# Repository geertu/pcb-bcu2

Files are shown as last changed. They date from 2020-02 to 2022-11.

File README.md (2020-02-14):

# BCU/2 - Board Control Unit Duo (KiCad PCB)

This is a small board to control operation of two development boards, e.g. on
your desk, or in a board farm.

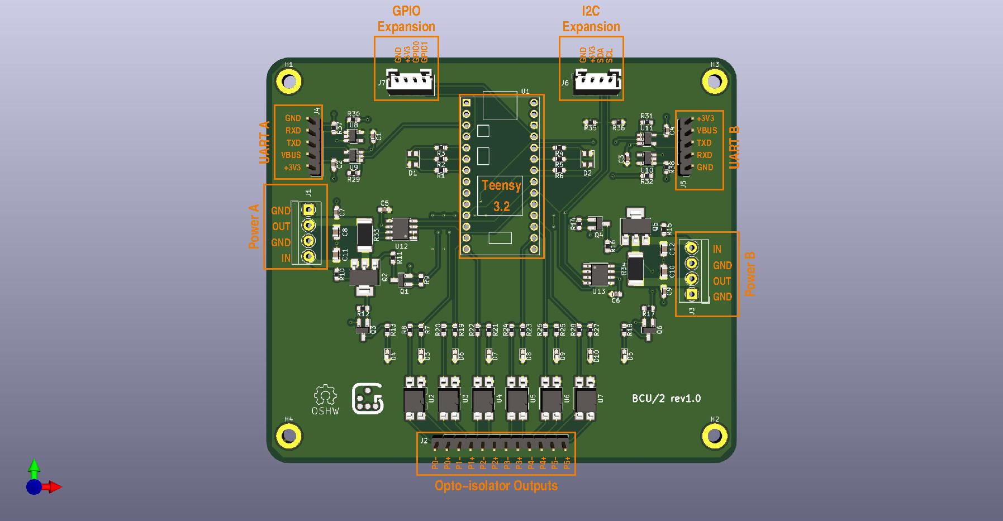
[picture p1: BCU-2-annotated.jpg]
PCB


## Features

  - Controlled by a Teensy 3.2 (https://www.pjrc.com/store/teensy32.html),
  - Two power control and measurement channels (3.3-14V, max. 3.2A),
  - Two UART channels
      - Optional buffer circuitry supports 1.8 to 5V, or fixed 3.3V,
      - Add external MAX3232 board for RS232-compatible voltage levels.
  - Six opto-isolators for e.g. reset, wake-up, and keypress simulation,
  - Two RGB status LEDs,
  - 4-pin I2C expansion connector,
  - 4-pin GPIO expansion connector.

## Software

Software to run on the Teensy is available from
https://github.com/geertu/teensy3-bcu2 in source form.

## License

CC-BY-SA-4.0 (https://creativecommons.org/licenses/by-sa/4.0/)

## PCB and Parts

PCB and parts can be ordered at
https://aisler.net/geert/board-control-unit/bcu-2 (Disclaimer: I'm not
affiliated to AISLER)

## Bill Of Materials

  - C1-C4[A], C5-C7, C9: Capacitor, 100nF, SMD 0603/1608
  - C8, C10-C12: Capacitor, 10µF, SMD 0805/2012, 25V
  - D1, D2: LED RGB Diffused, Common Anode at pin 1, SMD 4PLCC
  - D3, D6-D10: LED Yellow clear, SMD 0603/1608
  - D4, D5: LED Green clear, SMD 0603/1608
  - J1, J3: Screw type, terminal block, RM 3.5mm
  - J2: Male 1x12 header 2.54mm
  - J4, J5: Male 1x5 header, RM 2.54mm
  - J6, J7: Male 1x4 header, RM 2mm, e.g. JST B4B-PH-K
  - J8-J9[B]: Male 1x14 header, RM 2.54mm
  - J10-J11[B]: Female 1x14 header, RM 2.54mm
  - Q1, Q3, Q4, Q6: MOSFET N-channel 60V 115mA, SOT23-3
  - Q2, Q5: MOSFET P-channel 20V 10A, SOT223
  - R1, R4: Resistor, 680Ω, SMD 0603/1608
  - R2, R3, R5, R6: Resistor, 100Ω, SMD 0603/1608
  - R7, R13, R18, R19, R21, R23, R25, R27: Resistor, 1kΩ, SMD 0603/1608
  - R8, R20, R22, R24, R26, R28: Resistor, 270Ω, SMD 0603/1608
  - R9, R14: Resistor, 10kΩ, SMD 0603/1608
  - R10, R11, R15, R16, R37[A], R38[A]: Resistor, 47kΩ, SMD 0603/1608
  - R12, R17: Resistor, 100kΩ, SMD 0603/1608
  - R29-R32[C]: Resistor, 0Ω, SMD 0603/1608
  - R33, R34: Resistor, 100mΩ, SMD 2512/6432, 1%, 2W
  - R35, R36: Resistor, 4.7kΩ, SMD 0603/1608
  - U1: Teensy 3.2
  - U2-U7: Opto-isolator, Mini-Flat-4, e.g. Broadcom HCPL-181-00CE
  - U8-U11[A]: 2-input AND gate 74LV1T08[D], SOT23-5
  - U12, U13: INA219xID power monitor, 8-SOIC

## Connector pinouts

  - J1 / J3: Power channels A & B

    Pin | Function
    --- | --------
     1  | GND
     2  | Power OUT
     3  | GND
     4  | Power IN (3.3-14V, max. 3.2A)

  - J2: Opto-isolator channels 0-5

    Pin               | Function
    ----------------- | --------
     1-11 (odd pins)  | Emitter ("negative output")
     2-12 (even pins) | Collector ("positive output")

  - J4 / J5: UART channels A & B

    Pin | Function
    --- | --------
     1  | GND
     2  | RXD
     3  | TXD
     4  | VBUS (1.8V to 5V), may be jumpered to +3V3
     5  | +3.3V[E]

  - J6: I2C expansion[F]

    Pin | Function
    --- | --------
     1  | GND
     2  | +3.3V[E]
     3  | SDA
     4  | SCL

  - J7: GPIO expansion[F]

    Pin | Function
    --- | --------
     1  | GND
     2  | +3.3V[E]
     3  | GPIO0
     4  | GPIO1

## Footnotes

  * [A] Optional buffer circuitry, mutually exclusive with [C]
  * [B] For Teensy plugin, not on schematic
  * [C] Optional buffer bypass, mutually exclusive with [A]
  * [D] Replace by 74LV1T00 for inverted TXD/RXD logic
  * [E] Maximum current output on the +3.3V pin of the Teensy 3.2 is 250 mA.
	Up to 100-125 mA can be used by expansion peripherals.
  * [F] Pin order of the I2C and GPIO expansion connectors is similar (but
	reversed!) to the Seeed Studio Grove and SparkFun Qwiic Connect
	systems, although the connector used is different (you can probably
	mount a real Grove connector instead).

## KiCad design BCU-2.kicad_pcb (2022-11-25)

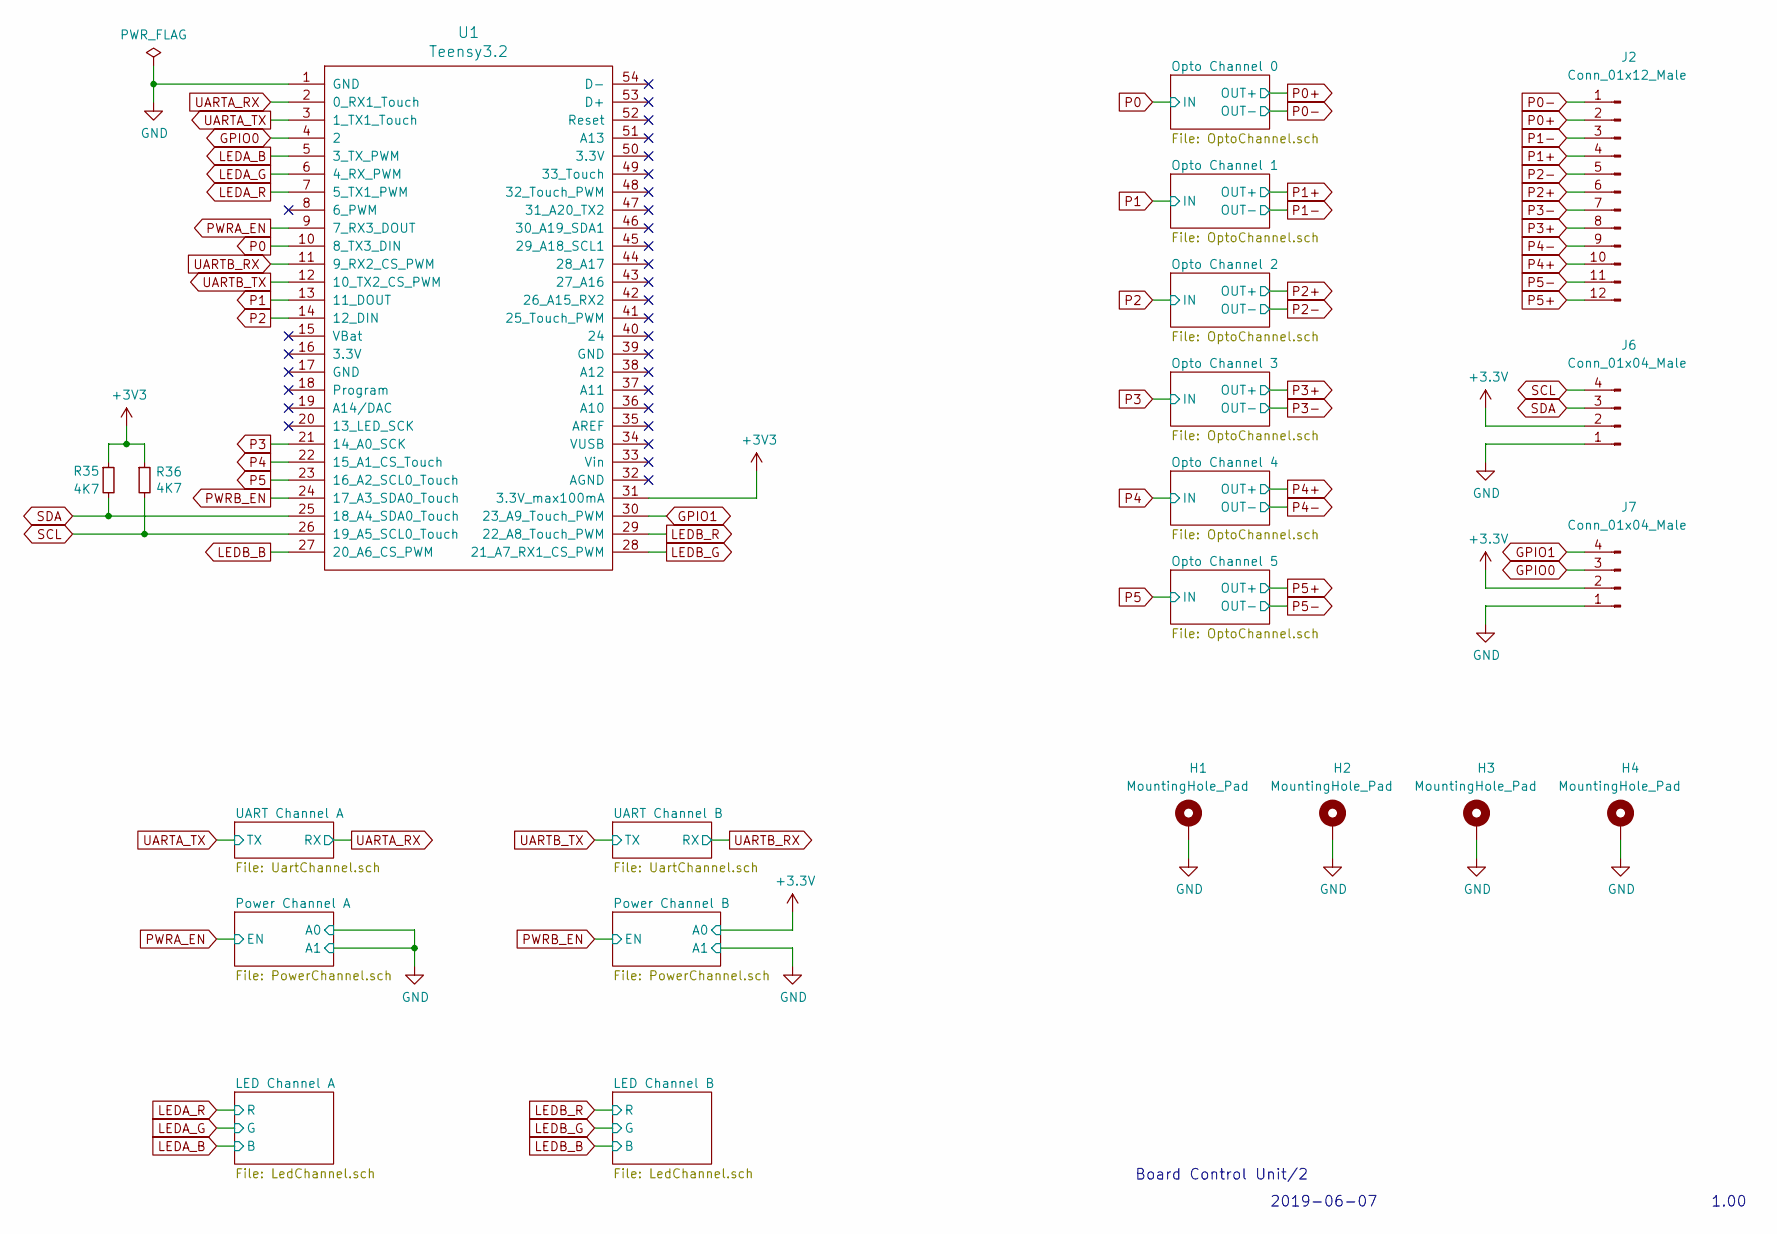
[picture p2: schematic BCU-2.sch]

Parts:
H1, H2, H3, H4: MountingHole_Pad; MountingHole_3.2mm_M3_DIN965_Pad
J2: Conn_01x12_Male; PinHeader_1x12_P2.54mm_Vertical
J6, J7: Conn_01x04_Male; JST_PH_B4B-PH-K_1x04_P2.00mm_Vertical
R35, R36: 4K7; R_0603_1608Metric_Pad1.05x0.95mm_HandSolder
U1: Teensy3.2; Teensy32-DIP28

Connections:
+3V3: J6.2, J7.2, R35.1, R36.1, U1.31 (3.3V_max100mA); also elsewhere on the board
GND: H1.1, H2.1, H3.1, H4.1, J6.1, J7.1, U1.1 (GND); also elsewhere on the board
GPIO0: J7.3, U1.4 (2)
GPIO1: J7.4, U1.30 (23_A9_Touch_PWM)
LEDA_B: U1.5 (3_TX_PWM); also elsewhere on the board
LEDA_G: U1.6 (4_RX_PWM); also elsewhere on the board
LEDA_R: U1.7 (5_TX1_PWM); also elsewhere on the board
LEDB_B: U1.27 (20_A6_CS_PWM); also elsewhere on the board
LEDB_G: U1.28 (21_A7_RX1_CS_PWM); also elsewhere on the board
LEDB_R: U1.29 (22_A8_Touch_PWM); also elsewhere on the board
P0: U1.10 (8_TX3_DIN); also elsewhere on the board
P0+: J2.2; also elsewhere on the board
P0-: J2.1; also elsewhere on the board
P1: U1.13 (11_DOUT); also elsewhere on the board
P1+: J2.4; also elsewhere on the board
P1-: J2.3; also elsewhere on the board
P2: U1.14 (12_DIN); also elsewhere on the board
P2+: J2.6; also elsewhere on the board
P2-: J2.5; also elsewhere on the board
P3: U1.21 (14_A0_SCK); also elsewhere on the board
P3+: J2.8; also elsewhere on the board
P3-: J2.7; also elsewhere on the board
P4: U1.22 (15_A1_CS_Touch); also elsewhere on the board
P4+: J2.10; also elsewhere on the board
P4-: J2.9; also elsewhere on the board
P5: U1.23 (16_A2_SCL0_Touch); also elsewhere on the board
P5+: J2.12; also elsewhere on the board
P5-: J2.11; also elsewhere on the board
PWRA_EN: U1.9 (7_RX3_DOUT); also elsewhere on the board
PWRB_EN: U1.24 (17_A3_SDA0_Touch); also elsewhere on the board
SCL: J6.4, R36.2, U1.26 (19_A5_SCL0_Touch); also elsewhere on the board
SDA: J6.3, R35.2, U1.25 (18_A4_SDA0_Touch); also elsewhere on the board
UARTA_RX: U1.2 (0_RX1_Touch); also elsewhere on the board
UARTA_TX: U1.3 (1_TX1_Touch); also elsewhere on the board
UARTB_RX: U1.11 (9_RX2_CS_PWM); also elsewhere on the board
UARTB_TX: U1.12 (10_TX2_CS_PWM); also elsewhere on the board

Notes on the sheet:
Board Control Unit/2
2019-06-07
1.00

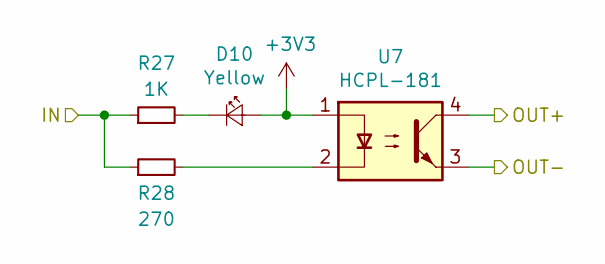
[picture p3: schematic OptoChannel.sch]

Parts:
D3: Yellow; LED_0603_1608Metric_Castellated
R7: 1K; R_0603_1608Metric_Pad1.05x0.95mm_HandSolder
R8: 270; R_0603_1608Metric_Pad1.05x0.95mm_HandSolder
U2: HCPL-181; SMDIP-4_W7.62mm

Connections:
+3V3: D3.2 (A), U2.1; also elsewhere on the board
unnamed: D3.1 (K), R7.2
unnamed: R8.2, U2.2
P0: R7.1, R8.1; also elsewhere on the board
P0+: U2.4; also elsewhere on the board
P0-: U2.3; also elsewhere on the board

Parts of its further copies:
D6, D7, D8, D9, D10: Yellow; LED_0603_1608Metric_Castellated
R19, R21, R23, R25, R27: 1K; R_0603_1608Metric_Pad1.05x0.95mm_HandSolder
R20, R22, R24, R26, R28: 270; R_0603_1608Metric_Pad1.05x0.95mm_HandSolder
U3, U4, U5, U6, U7: HCPL-181; SMDIP-4_W7.62mm

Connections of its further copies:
+3V3: D6.2 (A), D7.2 (A), D8.2 (A), D9.2 (A), D10.2 (A), U3.1, U4.1, U5.1, U6.1, U7.1; also elsewhere on the board
unnamed: D6.1 (K), R19.2
unnamed: D7.1 (K), R21.2
unnamed: D8.1 (K), R23.2
unnamed: D9.1 (K), R25.2
unnamed: D10.1 (K), R27.2
unnamed: R20.2, U3.2
unnamed: R22.2, U4.2
unnamed: R24.2, U5.2
unnamed: R26.2, U6.2
unnamed: R28.2, U7.2
P1: R19.1, R20.1; also elsewhere on the board
P1+: U3.4; also elsewhere on the board
P1-: U3.3; also elsewhere on the board
P2: R21.1, R22.1; also elsewhere on the board
P2+: U4.4; also elsewhere on the board
P2-: U4.3; also elsewhere on the board
P3: R23.1, R24.1; also elsewhere on the board
P3+: U5.4; also elsewhere on the board
P3-: U5.3; also elsewhere on the board
P4: R25.1, R26.1; also elsewhere on the board
P4+: U6.4; also elsewhere on the board
P4-: U6.3; also elsewhere on the board
P5: R27.1, R28.1; also elsewhere on the board
P5+: U7.4; also elsewhere on the board
P5-: U7.3; also elsewhere on the board

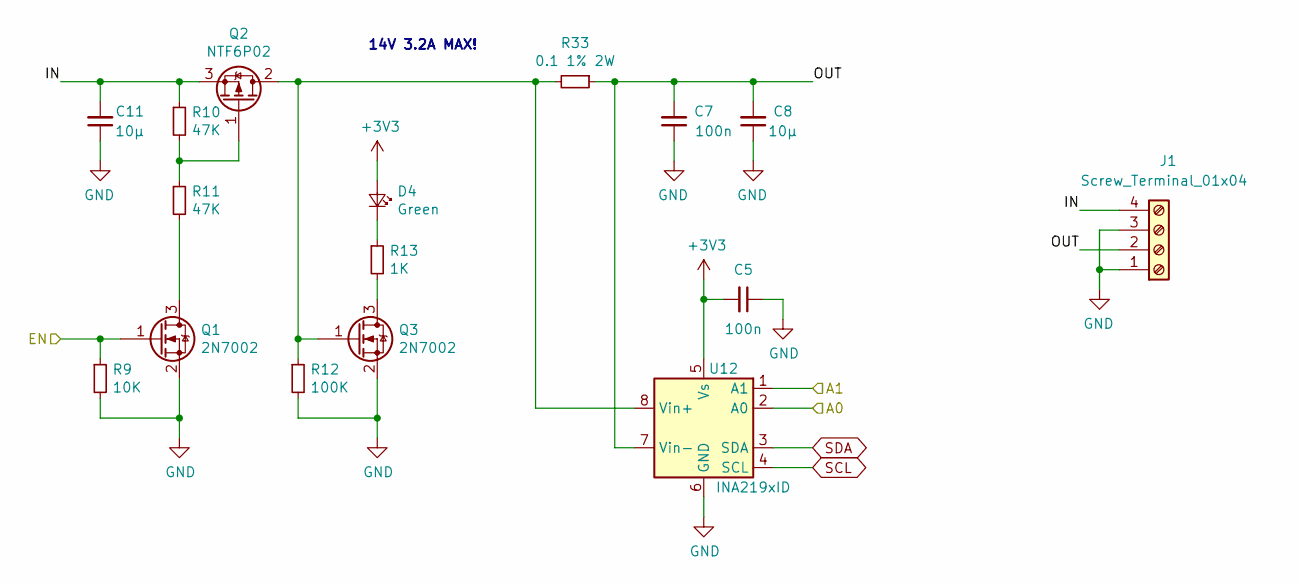
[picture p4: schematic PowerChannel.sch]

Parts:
C6, C9: 100n; C_0603_1608Metric_Pad1.05x0.95mm_HandSolder
C10, C12: 10µ; C_0805_2012Metric_Pad1.15x1.40mm_HandSolder
D4: Green; LED_0603_1608Metric_Castellated
J1: Screw_Terminal_01x04; TerminalBlock_MetzConnect_Type059_RT06304HBWC_1x04_P3.50mm_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
Q1, Q3: 2N7002; SOT-23_Handsoldering
Q2: NTF6P02; SOT-223-3_TabPin2
R9: 10K; R_0603_1608Metric_Pad1.05x0.95mm_HandSolder
R10, R11: 47K; R_0603_1608Metric_Pad1.05x0.95mm_HandSolder
R12: 100K; R_0603_1608Metric_Pad1.05x0.95mm_HandSolder
R13: 1K; R_0603_1608Metric_Pad1.05x0.95mm_HandSolder
R34: 0.1 1% 2W; R_2512_6332Metric_Pad1.52x3.35mm_HandSolder
U12: INA219xID; SOIC-8_3.9x4.9mm_P1.27mm

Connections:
+3V3: C6.2, D4.2 (A), U12.5 (Vs); also elsewhere on the board
GND: C6.1, C9.1, C10.1, C12.1, J1.1, J1.3, Q1.2 (S), Q3.2 (S), R9.2, R12.2, U12.1 (A1), U12.2 (A0), U12.6 (GND); also elsewhere on the board
unnamed: D4.1 (K), R13.1
unnamed: Q1.3 (D), R11.2
unnamed: Q2.1 (G), R10.2, R11.1
unnamed: Q3.3 (D), R13.2
PWRA_EN: Q1.1 (G), R9.1; also elsewhere on the board
SCL: U12.4 (SCL); also elsewhere on the board
SDA: U12.3 (SDA); also elsewhere on the board

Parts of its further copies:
C5, C7: 100n; C_0603_1608Metric_Pad1.05x0.95mm_HandSolder
C8, C11: 10µ; C_0805_2012Metric_Pad1.15x1.40mm_HandSolder
D5: Green; LED_0603_1608Metric_Castellated
J3: Screw_Terminal_01x04; TerminalBlock_MetzConnect_Type059_RT06304HBWC_1x04_P3.50mm_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
Q4, Q6: 2N7002; SOT-23_Handsoldering
Q5: NTF6P02; SOT-223-3_TabPin2
R14: 10K; R_0603_1608Metric_Pad1.05x0.95mm_HandSolder
R15, R16: 47K; R_0603_1608Metric_Pad1.05x0.95mm_HandSolder
R17: 100K; R_0603_1608Metric_Pad1.05x0.95mm_HandSolder
R18: 1K; R_0603_1608Metric_Pad1.05x0.95mm_HandSolder
R33: 0.1 1% 2W; R_2512_6332Metric_Pad1.52x3.35mm_HandSolder
U13: INA219xID; SOIC-8_3.9x4.9mm_P1.27mm

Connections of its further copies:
+3V3: C5.2, D5.2 (A), U13.2 (A0), U13.5 (Vs); also elsewhere on the board
GND: C5.1, C7.1, C8.1, C11.1, J3.1, J3.3, Q4.2 (S), Q6.2 (S), R14.2, R17.2, U13.1 (A1), U13.6 (GND); also elsewhere on the board
unnamed: D5.1 (K), R18.1
unnamed: Q4.3 (D), R16.2
unnamed: Q5.1 (G), R15.2, R16.1
unnamed: Q6.3 (D), R18.2
PWRB_EN: Q4.1 (G), R14.1; also elsewhere on the board
SCL: U13.4 (SCL); also elsewhere on the board
SDA: U13.3 (SDA); also elsewhere on the board

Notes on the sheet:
14V 3.2A MAX!

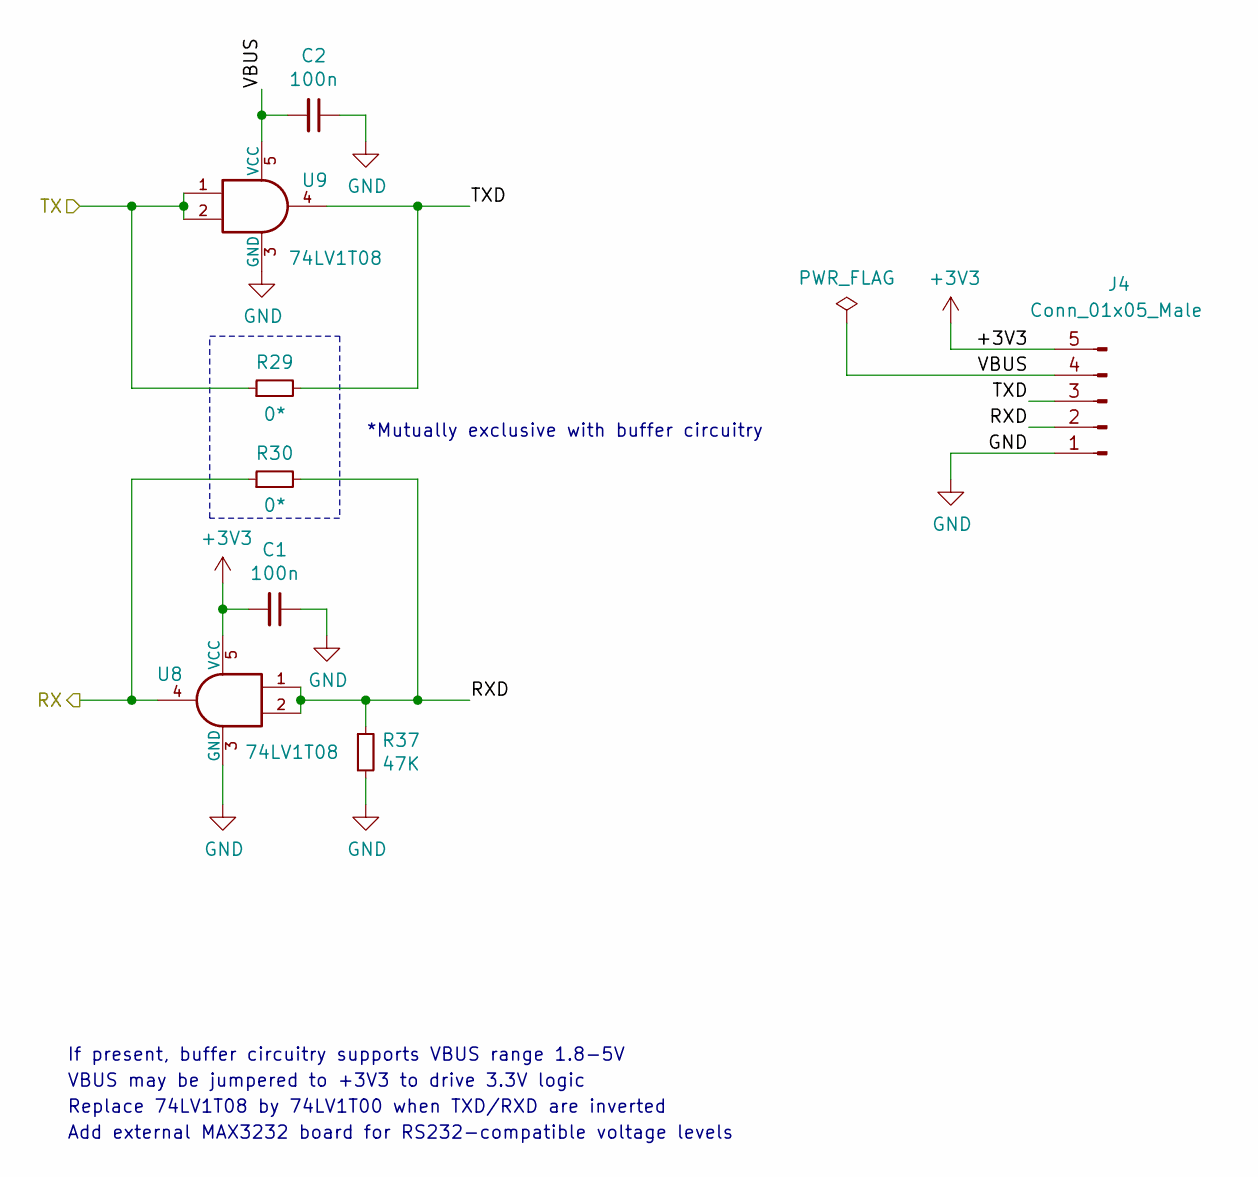
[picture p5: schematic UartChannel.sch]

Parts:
C1, C2: 100n; C_0603_1608Metric_Pad1.05x0.95mm_HandSolder
J4: Conn_01x05_Male; PinHeader_1x05_P2.54mm_Vertical
R29, R30: 0*; R_0603_1608Metric_Pad1.05x0.95mm_HandSolder
R37: 47K; R_0603_1608Metric_Pad1.05x0.95mm_HandSolder
U8, U9: 74LV1T08; SOT-23-5_HandSoldering

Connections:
+3V3: C1.2, J4.5, U8.5 (VCC); also elsewhere on the board
/UART Channel A/RXD: J4.2, R30.2, R37.1, U8.1, U8.2
/UART Channel A/TXD: J4.3, R29.2, U9.4
/UART Channel A/VBUS: C2.2, J4.4, U9.5 (VCC)
GND: C1.1, C2.1, J4.1, R37.2, U8.3 (GND), U9.3 (GND); also elsewhere on the board
UARTA_RX: R30.1, U8.4; also elsewhere on the board
UARTA_TX: R29.1, U9.1, U9.2; also elsewhere on the board

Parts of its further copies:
C3, C4: 100n; C_0603_1608Metric_Pad1.05x0.95mm_HandSolder
J5: Conn_01x05_Male; PinHeader_1x05_P2.54mm_Vertical
R31, R32: 0*; R_0603_1608Metric_Pad1.05x0.95mm_HandSolder
R38: 47K; R_0603_1608Metric_Pad1.05x0.95mm_HandSolder
U10, U11: 74LV1T08; SOT-23-5_HandSoldering

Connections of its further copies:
+3V3: C3.2, J5.5, U10.5 (VCC); also elsewhere on the board
/UART Channel B/RXD: J5.2, R32.2, R38.1, U10.1, U10.2
/UART Channel B/TXD: J5.3, R31.2, U11.4
/UART Channel B/VBUS: C4.2, J5.4, U11.5 (VCC)
GND: C3.1, C4.1, J5.1, R38.2, U10.3 (GND), U11.3 (GND); also elsewhere on the board
UARTB_RX: R32.1, U10.4; also elsewhere on the board
UARTB_TX: R31.1, U11.1, U11.2; also elsewhere on the board

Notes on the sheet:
*Mutually exclusive with buffer circuitry
If present, buffer circuitry supports VBUS range 1.8-5V
Replace 74LV1T08 by 74LV1T00 when TXD/RXD are inverted
VBUS may be jumpered to +3V3 to drive 3.3V logic
Add external MAX3232 board for RS232-compatible voltage levels

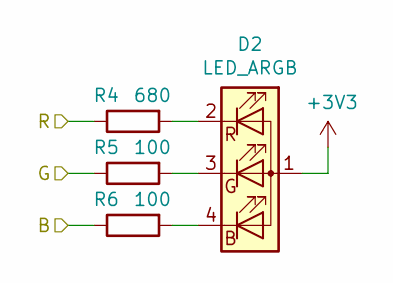
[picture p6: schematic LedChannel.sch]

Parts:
D1: LED_ARGB; LED_Cree-PLCC4_3.2x2.8mm_CCW
R1: 680; R_0603_1608Metric_Pad1.05x0.95mm_HandSolder
R2, R3: 100; R_0603_1608Metric_Pad1.05x0.95mm_HandSolder

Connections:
+3V3: D1.1 (A); also elsewhere on the board
LEDA_B: R3.1; also elsewhere on the board
LEDA_G: R2.1; also elsewhere on the board
LEDA_R: R1.1; also elsewhere on the board
unnamed: D1.2 (RK), R1.2
unnamed: D1.3 (GK), R2.2
unnamed: D1.4 (BK), R3.2

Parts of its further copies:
D2: LED_ARGB; LED_Cree-PLCC4_3.2x2.8mm_CCW
R4: 680; R_0603_1608Metric_Pad1.05x0.95mm_HandSolder
R5, R6: 100; R_0603_1608Metric_Pad1.05x0.95mm_HandSolder

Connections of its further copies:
+3V3: D2.1 (A); also elsewhere on the board
LEDB_B: R6.1; also elsewhere on the board
LEDB_G: R5.1; also elsewhere on the board
LEDB_R: R4.1; also elsewhere on the board
unnamed: D2.2 (RK), R4.2
unnamed: D2.3 (GK), R5.2
unnamed: D2.4 (BK), R6.2

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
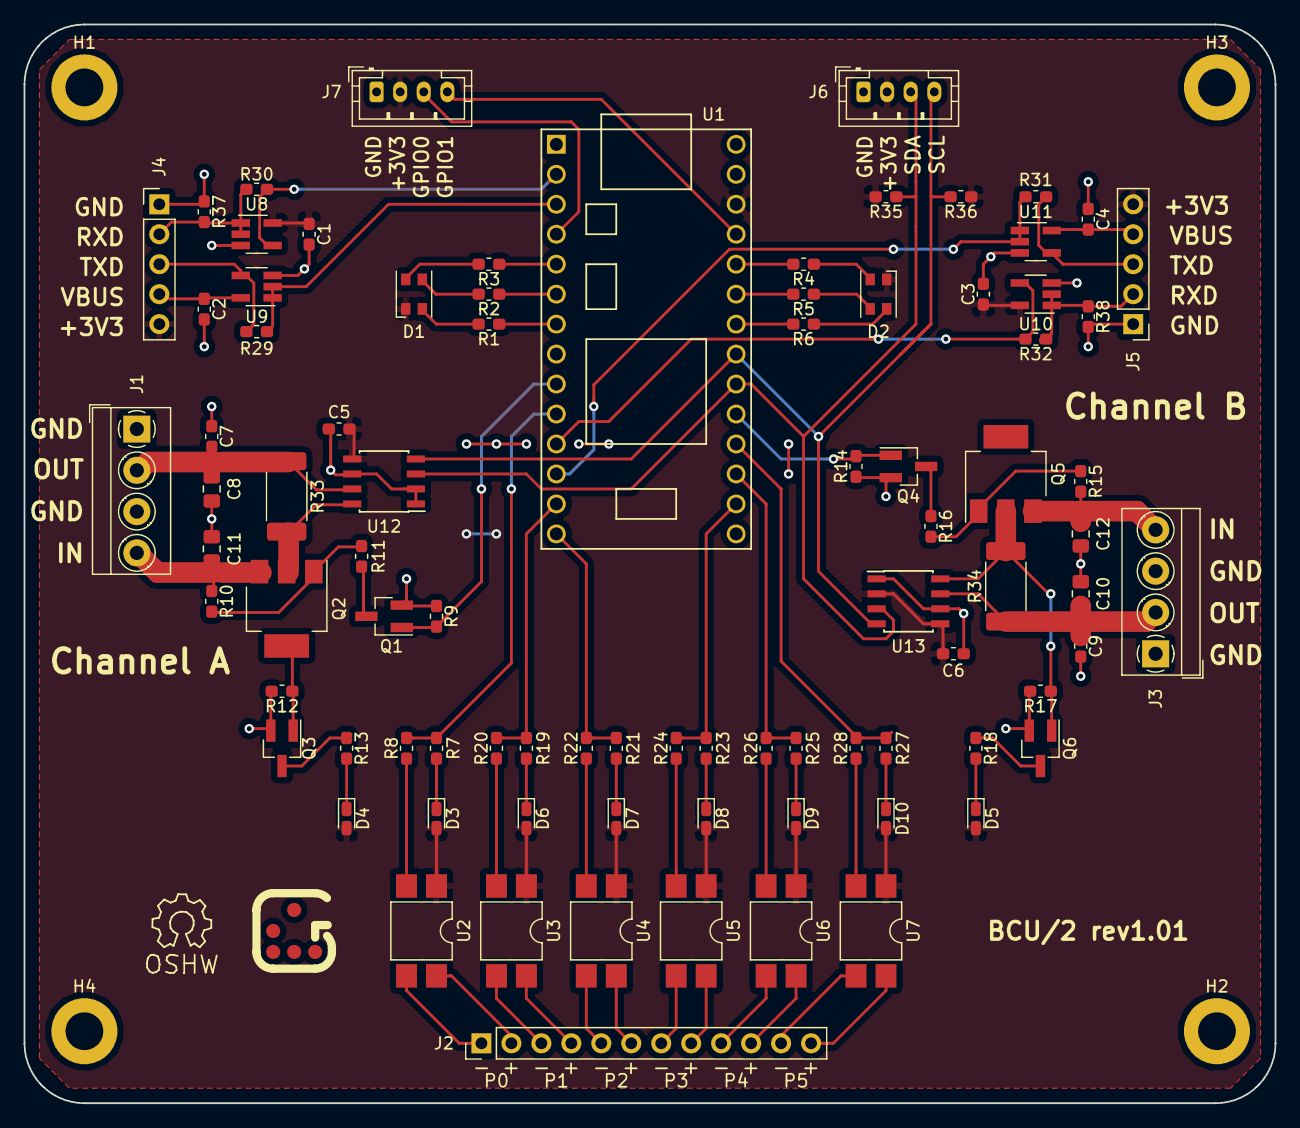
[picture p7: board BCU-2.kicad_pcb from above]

Board: 2 copper layers, 106.0 x 91.4 mm, 92 parts (0 on the bottom side), 74 nets.

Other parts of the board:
Glider: Glider logo; Glider_bvba_G_Medium
OSHW: Symbol_OSHW-Logo_SilkScreen

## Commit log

2019-06-12 Import 74LV1T08 component (single AND gate)
    Including power pins.
2019-06-12 Import schematic and PCB
    [BCU-2.kicad_pcb, BCU-2.sch, LedChannel.sch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]
2020-02-13 Use tables for connector pinouts
2020-02-14 Add PCB image
2022-11-25 Improve silkscreen for rev1.01
    [BCU-2.kicad_pcb]
